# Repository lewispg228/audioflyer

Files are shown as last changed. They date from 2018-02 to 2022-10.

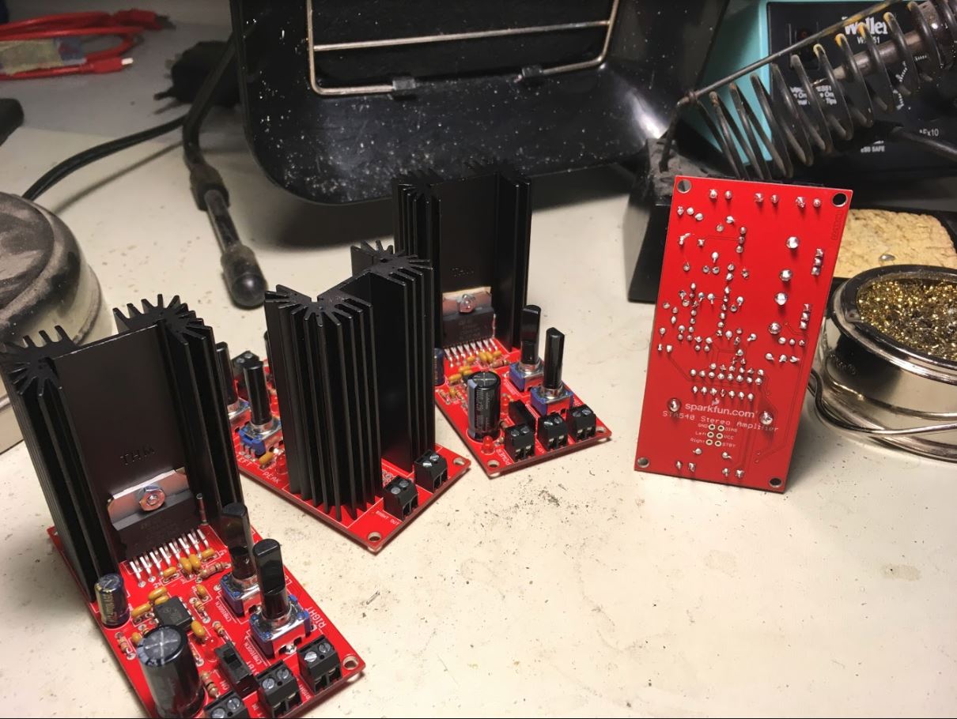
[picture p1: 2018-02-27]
pics/amps_assembled.JPG

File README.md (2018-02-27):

# audioflyer
Surround sound audio mixing controlled by serial commands. Making mixes that fly!

Why? Because this is going to be awesome.

The plan is to use a SparkFun Tsunami Wav Trigger board to play lots of audio files. To start off, I plan to use some tasty guitar riffs and various reverbs/effects. Maybe bass, drums and vocals. We shall see. Then play these tracks through a set of 8 speakers arranged in something similar to 7.1 surround.

For amplification, I am using four SparkFun Audio Amps. They are stereo amps, so this will get me 8 channels.

I hope to start many tracks at the same time, and then control their volume in all 8 tracks with serial commands from a micro controller - probably an arduino. I love the idea of using some code to pull off some smooth motions, spatial movements, rotation of the entire mix around my head, "fly by" guitar solos, and even some volume tricks that may be close to impossible to pull off with manual moving of faders, and a big pain to draw in on automation control tracks. This could mean that I want the snare to spin around my head every time I hit it. It might prove to be annoying, but it might also be totally awesome! What about using the random function in arduino to place where each instrument will live for each mix - it means that every listening experience would be unique - pretty F-in' cool if you ask me.

What got me turned onto this idea was binaural recordings. It's basically a technique that's been around for a long time where you put tiny microphones in your ears (facing outward) or you put them on a dummy head, and then record both mics. When you listen to them back on headphones, you can really hear the position of all the sounds. I guess it has something to do with how our brains calculate time differences and bass roll off difference between each ear. Wild stuff! I bought a pair of these mics from The Sound Professionals for 79 bucks and they sound amazing! I can't wait to track some crazy surround sound mixes and then be able to listen back on headphones anywhere and hear the awesome spatial automation.

This has bound to have been done before... but maybe not? I'm not interested in just rocking 5.1 or 7.1 surround mixes with fancy sound cards and cool plugins. I want to control the entire mix from code on a micro. This will open the door to new sound movement effects that I can't even predict at this time.

All I need is volume control for each track to each output. From reading about the Tsunami, it sounds like this is very possible.

How hard can it be?

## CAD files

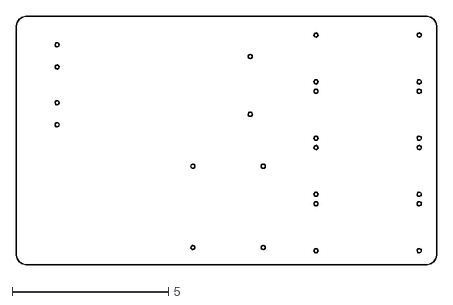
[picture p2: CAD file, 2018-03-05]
base_plate/base_plate.dxf
13.5 x 7.95

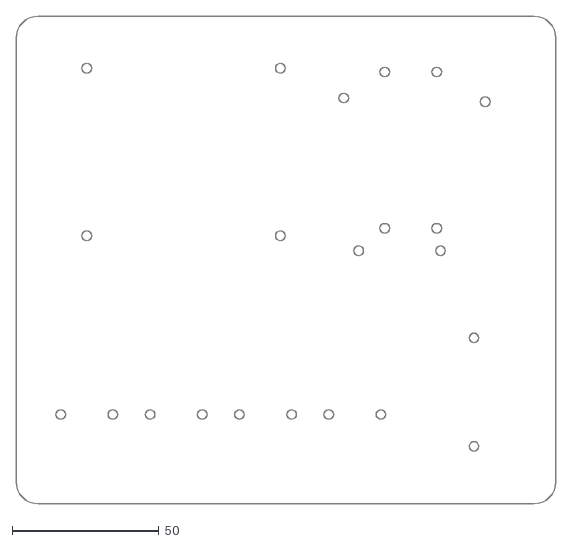
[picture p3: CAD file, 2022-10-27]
base_plate/Noisy_Crickets/base_plate_noisy_crickets.dxf
184.2 x 166.4

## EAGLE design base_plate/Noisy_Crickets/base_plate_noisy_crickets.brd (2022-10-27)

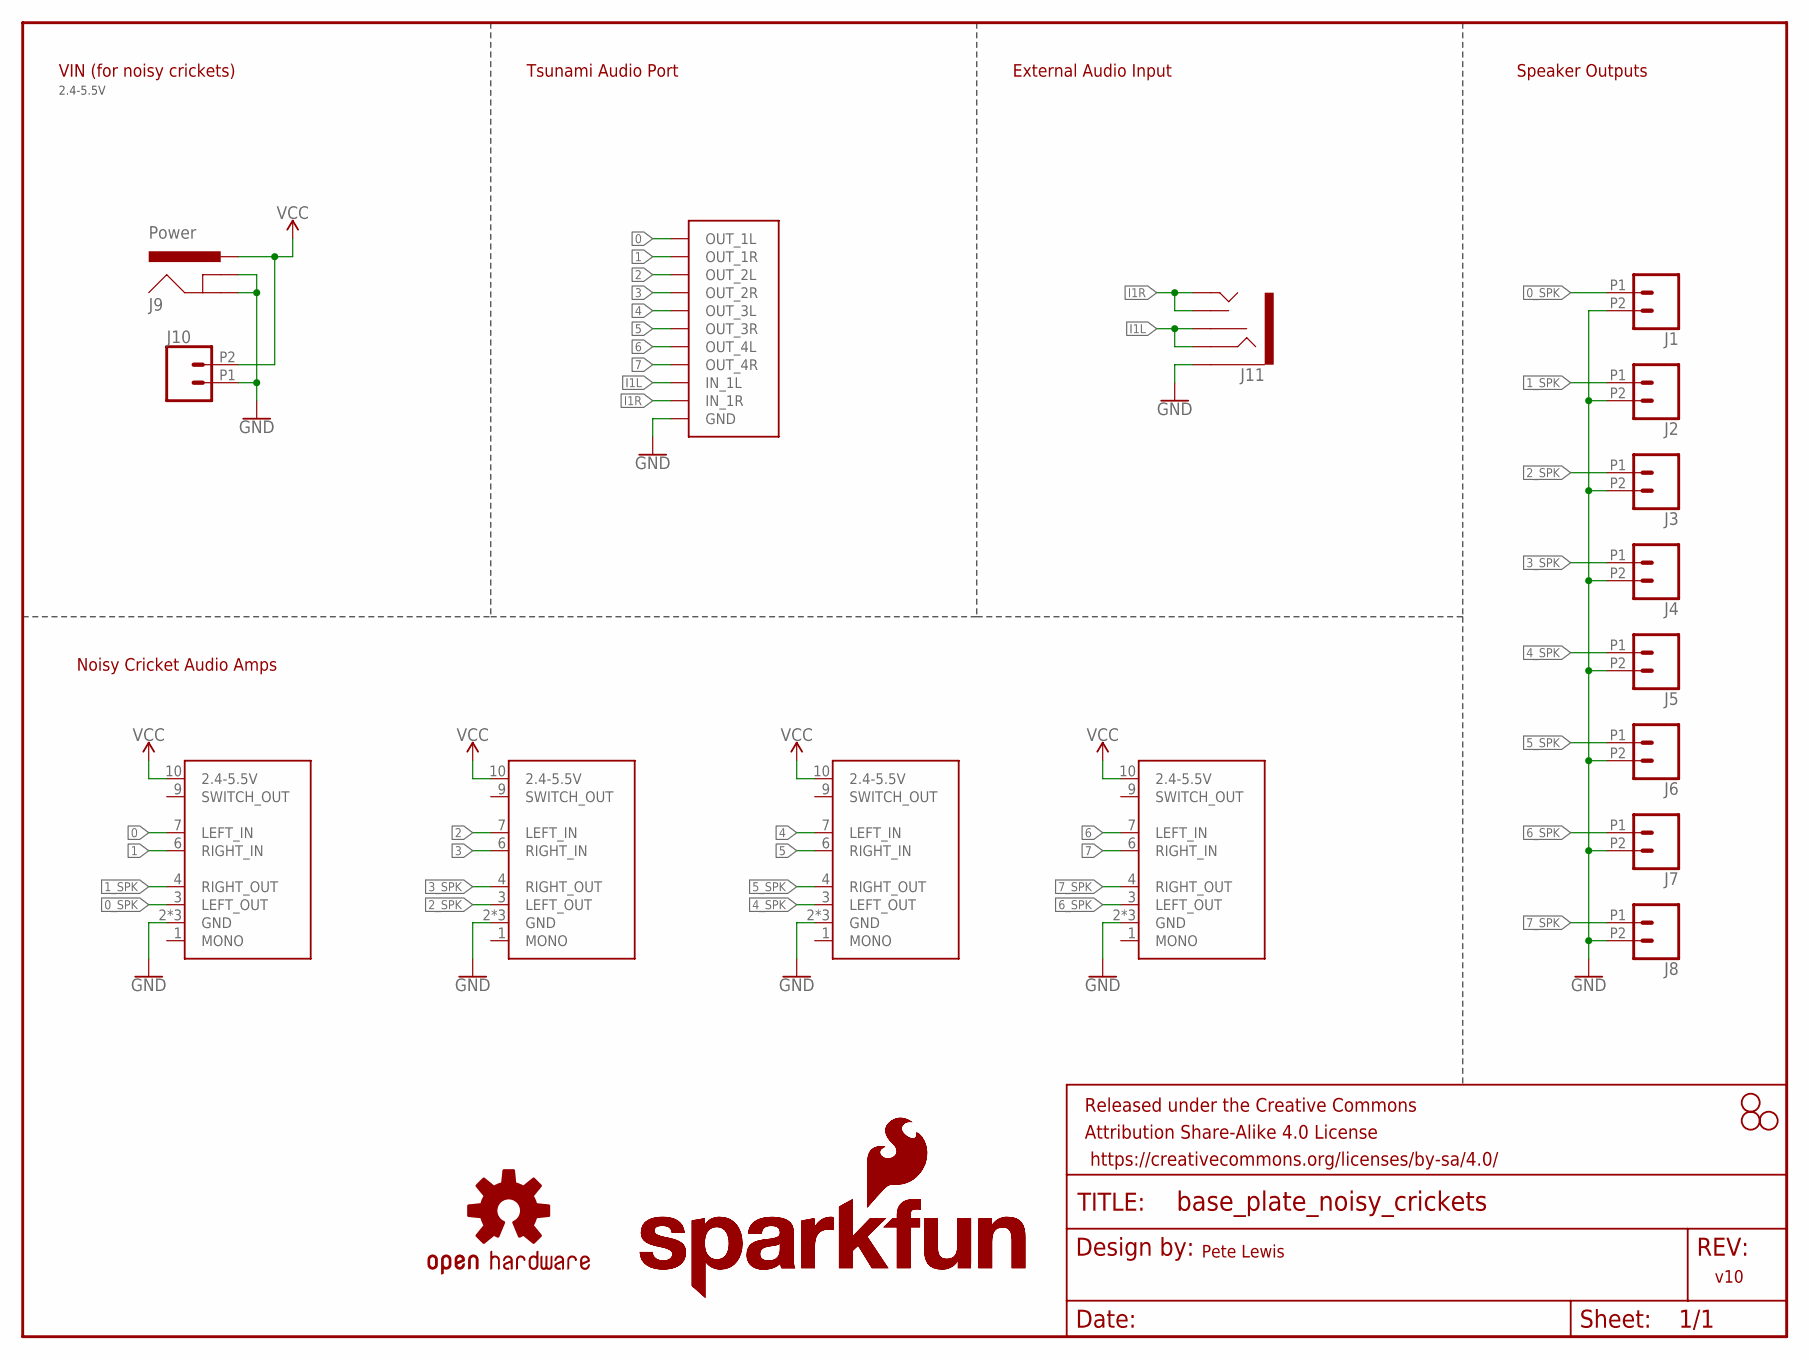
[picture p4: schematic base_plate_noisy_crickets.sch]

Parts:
FRAME1: FRAME-LETTER; CREATIVE_COMMONS
H1, H3, H4: STAND-OFFTIGHT; STAND-OFF-TIGHT
J1, J2, J3, J4, J5, J6, J7, J8, J10: CONN_022.54MM_SCREWTERM; 1X02_2.54_SCREWTERM
J9: Power; POWER_JACK_PTH_LOCK
J11: AUDIO_JACK_3.5MM_PTH; AUDIO-JACK
LOGO1: SFE_LOGO_NAME_FLAME.1_INCH; SFE_LOGO_NAME_FLAME_.1
LOGO2: OSHW-LOGOS; OSHW-LOGO-S
LOGO3: SFE_LOGO_NAME_FLAME.3_INCH; SFE_LOGO_NAME_FLAME_.3
U$1, U$2, U$3, U$4: NOISY_CRICKET; NOISY_CRICKET_W_PTH
U$5: TSUNAMI_AUDIO_PORTS

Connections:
0: U$1.7 (LEFT_IN), U$5.O1L (OUT_1L)
0_SPK: J1.P1 (1), U$1.3 (LEFT_OUT)
1: U$1.6 (RIGHT_IN), U$5.O1R (OUT_1R)
1_SPK: J2.P1 (1), U$1.4 (RIGHT_OUT)
2: U$2.7 (LEFT_IN), U$5.O2L (OUT_2L)
2_SPK: J3.P1 (1), U$2.3 (LEFT_OUT)
3: U$2.6 (RIGHT_IN), U$5.O2R (OUT_2R)
3_SPK: J4.P1 (1), U$2.4 (RIGHT_OUT)
4: U$3.7 (LEFT_IN), U$5.O3L (OUT_3L)
4_SPK: J5.P1 (1), U$3.3 (LEFT_OUT)
5: U$3.6 (RIGHT_IN), U$5.O3R (OUT_3R)
5_SPK: J6.P1 (1), U$3.4 (RIGHT_OUT)
6: U$4.7 (LEFT_IN), U$5.O4L (OUT_4L)
6_SPK: J7.P1 (1), U$4.3 (LEFT_OUT)
7: U$4.6 (RIGHT_IN), U$5.O4R (OUT_4R)
7_SPK: J8.P1 (1), U$4.4 (RIGHT_OUT)
GND: J1.P2 (2), J2.P2 (2), J3.P2 (2), J4.P2 (2), J5.P2 (2), J6.P2 (2), J7.P2 (2), J8.P2 (2), J9.GND, J9.GNDBREAK, J10.P1 (1), J11.SLEEVE, U$1.2 (GND), U$1.5 (GND), U$1.8 (GND), U$2.2 (GND), U$2.5 (GND), U$2.8 (GND), U$3.2 (GND), U$3.5 (GND), U$3.8 (GND), U$4.2 (GND), U$4.5 (GND), U$4.8 (GND), U$5.P$11 (GND), U$5.P$12 (GND), U$5.P$13 (GND), U$5.P$14 (GND), U$5.P$15 (GND), U$5.P$16 (GND), U$5.P$17 (GND), U$5.P$18 (GND), U$5.P$19 (GND), U$5.P$20 (GND)
I1L: J11.RING, J11.RSH, U$5.I1L (IN_1L)
I1R: J11.TIP, J11.TSH, U$5.I1R (IN_1R)
VCC: J9.PWR, J10.P2 (2), U$1.10 (2.4-5.5V), U$2.10 (2.4-5.5V), U$3.10 (2.4-5.5V), U$4.10 (2.4-5.5V)

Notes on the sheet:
Speaker Outputs
Noisy Cricket Audio Amps
VIN (for noisy crickets)
Tsunami Audio Port
External Audio Input
2.4-5.5V
Pete Lewis
v10

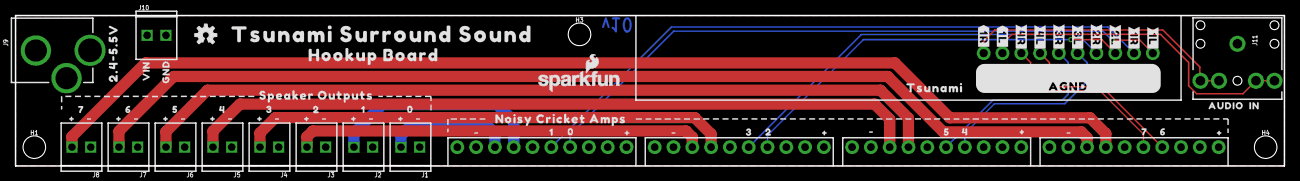
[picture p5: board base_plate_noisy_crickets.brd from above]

Board: 2 copper layers, 171.5 x 20.3 mm, 87 parts (1 on the bottom side), 20 nets.

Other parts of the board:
E$6: REDBOARD_ARTEMIS
E$8: THING_PLUS
U$6: AUDIO0
U$7: IN0
U$8, U$57: 00
U$9, U$58: 10
U$10, U$59: 20
U$11, U$60: 30
U$12, U$61: 40
U$13, U$62: 50
U$14, U$63: 60
U$15, U$64: 70
U$16, U$17, U$18, U$19, U$20, U$21, U$22, U$23, U$49, U$50, U$51, U$52: #0
U$24, U$25, U$26, U$27, U$28, U$29, U$30, U$32, U$48, U$53, U$54, U$55: #_0
U$31: VIN0
U$33: GND0
U$34: TSUNAMI_SURROUND_SOUND0
U$35: HOOKUP_BOARD0
U$36: 2#4#5#5V0
U$37: #AGND#0
U$38: #1R#0
U$39: #2L#0
U$40: #2R#0
U$41: #3R#0
U$42: #3L#0
U$43: #4L#0
U$44: #4R#0
U$45: #1L#0
U$46: NOISY_CRICKET_AMPS0
U$47: TSUNAMI0
U$56: SPEAKER_OUTPUTS0
U$65: TSUNAMI
U$116: #1L#3
U$164: #1R#3

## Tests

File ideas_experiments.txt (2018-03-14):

\\ Magic wand controller.

The participant gets to be in a circle of speakers. Each speaker has a sensor on it to detect if the participant is pointing his/her wand at it. That's where the sound comes from. Imagine mixing a track using this sort of tech. How fun would it be to position the drums/guitar/vocals/lead by pointint where you want them??!!

\\ Spinning speakers.

Put some speakers on a rotating stand - or maybe the speaker is pointint up into a 45 degree mirror that can rotate (to avoid having to deal with cable twisting). This would kind of be like a tremelo effect, but using the room sound to actually effect what you hear. How cool would that be??!!

\\ Listener lazy susan

Rotate the listener? What if I was on a chair that was on a rotating plateform (kind of a large lazy susan), while I record the mix in real time with my binaural mics in. I could rotate physiccally, instead of automating the audio around the speakers.... whoa... this could get wiggy.

\\ tube technology

Put some sounds through long tubes, rotate the tubes, total sonic awesomeness without explaination.

\\ Corrective EQ and (maybe) compression/limiting

Put a DSP chip (blender) that can conduct a hearing test and make a custom EQ per channel, flatten out the speaker, correct for any hearing loss for the listener. Possibly add in some limiting to protect the speakers and allow you to really not worry about maxing out a channel and damaging a speaker or the system in anyway.

\\ magical headphone experience - Realtime automation control to manican head, livestreamed to participant

Have a manican head mic setup with an array of speakers around it. (Use the 3Dio low end maybe?) Stream the audio from the mics to the participant's headphones. This way, the participant can be in a different environment - any room really - and the audio tricks (e/g/ moving the audio position) can happen in real time in the recording room. This would seem like the audio is coming from a speaker that doesn't exhist in the actual room that they are listening in. It would seem magical. Sense their rotational position and adjust the playback room/live stream accordingly.

\\ Blind fold experience?

What if the participant/listener was blind folded, and interacted with the space with either a magic wand or some sort of touch sensative surfaces (walls? Joystick?). Audio experience to the max. Tell a story by flying through the space. Make it a game to point where you think you hear the sound.

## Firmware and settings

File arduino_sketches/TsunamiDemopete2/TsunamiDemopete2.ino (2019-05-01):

// ****************************************************************************
//       Sketch: Tsunami Serial Control Example
// Date Created: 11/22/2016
//
//     Comments: Demonstrates advanced, two-way, serial control of the Tsunami
//               from a 3.3V Arduino.
//
//  Programmers: Jamie Robertson, info@robertsonics.com
//
//  WARNING: The Tsunami is a 3.3V device. Attempting to connect it to a 5V
//   Arduino (such as an UNO) without level-shifters, will likely damage your
//   Tsunami!
//
// ****************************************************************************
//
// To use this sketch with an Arduino, you'll need:
//
// 1) An Arduino with an operating voltage of 3.3V, *** NOT 5V ***!
// 2) Download and install the Metro library.
// 3) Connect 3 wires from the Arduino to the Tsunami's serial connector:
//
//    Arduino       Tsunami
//    =======       =======
//    GND  <------> GND
//    TXn  <------> RX
//    RXn  <------> TX
//
//    If you're using an Arduino with at least one extra hardware serial port,
//    such as an M0 or Teensy, the Tsunami library is already set to use
//    Serial1. If you need to change that, or want to use AltSoftSerial, you
//    must make a small edit the Tsunami.h file, according the instructions in
//    that file.
//
// 4) Download and install the demo wav files onto the Tsunami's microSD
//    card. You can find them here:
//
//    http://robertsonics.com/2015/04/25/arduino-serial-control-tutorial/
//
//    You can certainly use your own tracks instead, although the demo may
//    not make as much sense. If you do, make sure your tracks are at least
//    10 to 20 seconds long and have no silence at the start of the file.
//
// 5) Open the Arduino Serial Monitor window to see status messages.

#include <Metro.h>              // Include the Metro library header
#include <Tsunami.h>            // Include the Tsunami library header
#include <AltSoftSerial.h>    // Optional for using AltSoftSerial

#define LED 13                  // our LED

Tsunami tsunami;                // Our Tsunami object

Metro gLedMetro(500);           // LED blink interval timer
Metro gSeqMetro(6000);          // Sequencer state machine interval timer

byte gLedState = 0;             // LED State
int  gSeqState = 0;             // Main program sequencer state
int  gRateOffset = 0;           // Tsunami sample-rate offset
int  gNumTracks;                // Number of tracks on SD card

int delay_time = 100;

char gTsunamiVersion[VERSION_STRING_LEN];    // Tsunami version string


// ****************************************************************************
void setup() {
  
  // Serial monitor
  Serial.begin(9600);
 
  // Initialize the LED pin
  pinMode(LED,OUTPUT);
  digitalWrite(LED,gLedState);

  // We should wait for the Tsunami to finish reset before trying to send
  // commands.
  delay(1000);

  // Tsunami startup at 57600
  tsunami.start();
  delay(10);
  
  // Send a stop-all command and reset the sample-rate offset, in case we have
  //  reset while the Tsunami was already playing.
  tsunami.stopAllTracks();
  tsunami.samplerateOffset(0, 0);
  
  // Enable track reporting from the Tsunami
  tsunami.setReporting(true);
  
  // Allow time for the Tsunami to respond with the version string and
  //  number of tracks.
  delay(100); 
  
}


// ****************************************************************************
// This program uses a Metro timer to create a sequencer that steps through
//  states at 6 second intervals - you can change this rate above. Each state
//  Each state will demonstrate a Tsunami serial control feature.
//
//  In this example, some states wait for specific audio tracks to stop playing
//  before advancing to the next state.

void loop() {
  
int i;

  // Call update on the Tsunami to keep the track playing status current.
  tsunami.update();
  
  // Check if the sequencer timer has elapsed and perform the appropriate
  //  state action if so. States 3 and 5 wait for tracks to stop playing and
  //  are therefore not in the metro event. They are instead polled after the
  //  metro check.
  if (gSeqMetro.check() == 1) {
      
      switch (gSeqState) {
  
          // State 0: Demonstrates how to fade in a music track 
          case 0:
              delay_time = 10;
              // First retrieve and print the version and number of tracks        
              if (tsunami.getVersion(gTsunamiVersion, VERSION_STRING_LEN)) {
                  Serial.print(gTsunamiVersion);
                  Serial.print("\n");
                  gNumTracks = tsunami.getNumTracks();
                  Serial.print("Number of tracks = ");
                  Serial.print(gNumTracks);
                  Serial.print("\n");
              }
              else
                  Serial.print("WAV Trigger response not available");
              delay(delay_time);
              Serial.print("1");
              tsunami.stopAllTracks();
              tsunami.samplerateOffset(0, 0);        // Reset sample rate offset to 0
              delay(delay_time);
              Serial.print("2");
              tsunami.masterGain(0, 0);              // Reset the master gain to 0dB
              delay(delay_time);
              Serial.print("3");
              tsunami.trackGain(1, -40);             // Preset Track 2 gain to -40dB
              tsunami.trackGain(2, -40);
              delay(delay_time);
              Serial.print("4");
              tsunami.trackPlayPoly(1, 0, true);     // Start Track 2
              tsunami.trackPlayPoly(2, 1, true);
              delay(delay_time);
              tsunami.trackFade(1, 0, 50, false);  // Fade Track 2 to 0dB over 2 sec
              tsunami.trackFade(2, 0, 50, false);
              gSeqState = 1;                         // Advance to state 1
              while(1);
          break;

          // State 1: Demonstrates how to cross-fade music tracks
          case 1:
              Serial.print("5");
              tsunami.trackGain(1, -40);             // Preset Track 1 gain to -40dB
              tsunami.trackPlayPoly(1, 0, true);     // Start Track 1
              tsunami.trackFade(1, 0, 3000, false);  // Fade Track 1 up to 0db over 3 secs
              tsunami.update();
              delay(2000);                           // Wait 2 secs
              tsunami.trackFade(1, -40, 3000, true); // Fade Track 2 down to -40dB over 3 secs and stop
              //Serial.print("Waiting for Track 1 to finish... ");
              gSeqState = 3;                         // Advance to state 2
          break;
                                 
          // State 3: Honk the horn 2 times
          case 3:
              tsunami.trackPlayPoly(5, 0, true);     // Start Track 5 poly
              tsunami.update();
              delay(500);
              tsunami.trackStop(5);                  // Stop Track 5
              tsunami.update();
              delay(250);
              tsunami.trackPlayPoly(5, 0, true);     // Start Track 5 poly
              tsunami.update();
              delay(500);
              tsunami.trackStop(5);                  // Stop Track 5
              gSeqState = 4;                         // Advance to state 4
          break;
          
          // State 4: Fade out and stop dialog
          case 4:
              tsunami.trackLoop(4, 0);               // Disable Track 4 looping
              tsunami.trackFade(4, -50, 5000, true); // Fade Track 4 to -50dB and stop
              Serial.print("Waiting for Track 4 to finish... ");
              gSeqState = 5;                         // Advance to state 5
          break;
            
          // State 6: Demonstrates preloading tracks and starting them in sample-
          //  sync, and real-time samplerate control (pitch bending);
          case 6:
              tsunami.trackLoad(6, 0, true);         // Load and pause Track 6
              tsunami.trackLoad(7, 0, true);         // Load and pause Track 7
              tsunami.trackLoad(8, 0, true);         // Load and pause Track 8
              tsunami.resumeAllInSync();             // Start all in sample sync

              // Decrement the sample rate offset from 0 to -32767 (1 octave down)
              //  in 10 ms steps
              gRateOffset = 0;
              for (i = 0; i < 127; i++) {
                gRateOffset -= 256;
                tsunami.samplerateOffset(0, gRateOffset);
                delay(10);
              }
              gRateOffset = -32767;
              tsunami.samplerateOffset(0, gRateOffset);
              
              // Hold for 1 second
              delay(1000);
              
              // Now increment to +32767 (1 octave up) in 10ms steps
              for (i = 0; i < 255; i++) {
                gRateOffset += 256;
                tsunami.samplerateOffset(0, gRateOffset);
                delay(10);
              }
              gRateOffset = 32767;
              tsunami.samplerateOffset(0, gRateOffset);
              
              // Hold for 1 second, the stop all tracks
              delay(1000);
              tsunami.stopAllTracks();               // Stop all
              gSeqState = 0;                         // Advance to state 0
          break;
            
      } // switch
           
  } // if (gSeqState.check() == 1)
 
  // State 2: Wait for Track 2 to stop, then fade down the music and start the
  //  dialog track looping.
  if (gSeqState == 2) {
      gSeqMetro.reset();                             // Reset the sequencer metro
      if (!tsunami.isTrackPlaying(2)) {
          Serial.print("Track 2 done\n");
          tsunami.trackFade(1, -6, 500, false);      // Lower the music volume
          tsunami.trackLoop(4, 1);                   // Enable Track 4 looping
          tsunami.trackPlayPoly(4, 0, true);         // Start Track 4 poly
          gSeqState = 3;                             // Advance to state 3;
      }       
  }

  // State 5: Wait for Track 4 to stop, then play three tracks sequentially and
  //  stop all with a 5 sec fade to -50dB. This is how you can implement MIDI
  //  Note-On/Off control for: MIDI -> Arduino -> WAV Trigger.
  if (gSeqState == 5) {
      gSeqMetro.reset();
      if (!tsunami.isTrackPlaying(4)) {
          Serial.print("Track 4 done\n");
          tsunami.masterGain(0, -8);                 // Lower main volume
          tsunami.trackPlayPoly(6, 0, true);         // Play first note
          tsunami.update();
          delay(1000);
          tsunami.trackPlayPoly(7, 0, true);         // Play second note
          tsunami.update();
          delay(1000);
          tsunami.trackPlayPoly(8, 0, true);         // Play third note
          tsunami.update();
          delay(1000);
          tsunami.trackFade(6, -50, 5000, true);     // Fade Track 6 to -50dB and stop
          tsunami.trackFade(7, -50, 5000, true);     // Fade Track 7 to -50dB and stop
          tsunami.trackFade(8, -50, 5000, true);     // Fade Track 8 to -50dB and stop
          gSeqState = 6;
      }       
  }
  
  // If time to do so, toggle the LED
  if (gLedMetro.check() == 1) {
      if (gLedState == 0) gLedState = 1;
      else gLedState = 0;
      digitalWrite(LED, gLedState);
  } // if (gLedMetro.check() == 1)

  // Delay 30 msecs
  delay(30);
}

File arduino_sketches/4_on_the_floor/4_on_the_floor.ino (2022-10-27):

/*
  Audio Flyer
  SparkFun Electronics
  Pete Lewis
  Started: 5-18-2021
*/
#include "track_numbers.h"
#include "drum_beats.h"
#include "set_functions.h"

int delay_ms_tsunami_com = 10;

#include <Tsunami.h>            // Include the Tsunami library header
//#include <AltSoftSerial.h>    // Optional for using AltSoftSerial

Tsunami tsunami;                // Our Tsunami object

char gTsunamiVersion[VERSION_STRING_LEN];    // Tsunami version string
int  gNumTracks;                // Number of tracks on SD card

long bpm = 120; // beats per minute (how many 1/4 notes there are in a minute)

bool guitar_qued = 0;
int guitar_qued_track = 20;
int guitar_qued_channel = 0;

bool bass_qued = 0;
int bass_qued_track = 100;
int bass_qued_channel = 0;

void setup()
{

  Serial.begin(115200);
  Serial.println("Audio Flyer DEBUG ON");

  tsunami.start();
  delay(delay_ms_tsunami_com);
  // Send a stop-all command and reset the sample-rate offset, in case we have
  //  reset while the Tsunami was already playing.
  tsunami.stopAllTracks();
  delay(delay_ms_tsunami_com);
  tsunami.samplerateOffset(0, 0);
  delay(delay_ms_tsunami_com);
  tsunami.setReporting(false); // disable track reporting from the Tsunami
  delay(delay_ms_tsunami_com);
  tsunami.update(); // Call update to keep the track playing status current.
  delay(delay_ms_tsunami_com);
  tsunami.masterGain(0, 0); // Reset the master gain to 0dB
  delay(delay_ms_tsunami_com);

  if (tsunami.getVersion(gTsunamiVersion, VERSION_STRING_LEN)) {
    Serial.print(gTsunamiVersion);
    Serial.print("\n");
    gNumTracks = tsunami.getNumTracks();
    Serial.print("Number of tracks = ");
    Serial.print(gNumTracks);
    Serial.print("\n");
  }


  test_audio_playback();
  pinMode(2, INPUT_PULLUP);
}

void loop()
{

  while (digitalRead(2) == false) // if ya press hte button on D2, then it will play a cycle of the song...
  {
    set_four_on_the_floor();
    // guitar
    guitar_qued = 1;
    guitar_qued_track = 20;
    guitar_qued_channel = 1;
    // bass
    bass_qued = 1;
    bass_qued_track = 100;
    bass_qued_channel = 2;

    play_measure();
    guitar_qued_track = 21;
    guitar_qued = 1;
    guitar_qued_channel = random(3, 6);
    play_measure();
    play_measure();
    play_measure();

    // guitar
    guitar_qued = 1;
    guitar_qued_track = 20;
    guitar_qued_channel = 1;
    // bass
    bass_qued = 1;
    bass_qued_track = 100;
    bass_qued_channel = 2;

    play_measure();
    guitar_qued_track = 21;
    guitar_qued = 1;
    guitar_qued_channel = random(3, 6);
    play_measure();
    play_measure();
    play_measure();

    set_half_time_groove_ride();
    // guitar
    guitar_qued = 1;
    guitar_qued_track = 203;
    guitar_qued_channel = 1;
    // bass
    bass_qued = 1;
    bass_qued_track = 202;
    bass_qued_channel = 2;

    for(int i = 0 ; i < 8 ; i++)
    {
      play_measure();
    }
  }
}

void test_audio_playback()
{
  for (int i = 0 ; i < 8 ; i++)
  {
    //int track = i + 60; // 60 is the strat of some drum tracks
    //int channel = i; // play a track on each output (0-7)
    //Serial.print("track: ");
    //Serial.println(track);
    //tsunami.trackGain(track, -5);
    //delay(delay_ms_tsunami_com);
    //tsunami.trackPlayPoly(track, channel, false);
    play_track((11), i);
    delay(1000);
  }
}

void play_track(int track = 1, int channel = 0);

void play_track(int track, int channel)
{
  Serial.print("track: ");
  Serial.println(track);
  tsunami.trackGain(track, -5);
  delay(delay_ms_tsunami_com);
  tsunami.trackPlayPoly(track, channel, false);
  delay(delay_ms_tsunami_com);
}





void play_measure()
{
  // loop through all 16th bar time divisions,
  // play each WAV (or combo of WAVS) at each division.

  long start_time_micros = micros();

  for (int i = 0 ; i < 16 ; i++)
  {
    //int val = analogRead(A0);
    //bpm = map(val, 0, 1023, 0, 240);
    bpm = 134;
    Serial.print("bpm: ");
    Serial.println(bpm);

    if (kick[i] == 1) tsunami.trackLoad(kick_t, 0, false);
    delay(delay_ms_tsunami_com);
    if (snare[i] == 1) tsunami.trackLoad(snare_t, 0, false);
    delay(delay_ms_tsunami_com);
    if (hat[i] == 1) tsunami.trackLoad(hat_t, 0, false);
    delay(delay_ms_tsunami_com);
    if (ride[i] == 1) tsunami.trackLoad(ride_t, 0, false);
    delay(delay_ms_tsunami_com);
    if (guitar_qued == 1)
    {
      tsunami.trackLoad(guitar_qued_track, guitar_qued_channel, false);
      delay(delay_ms_tsunami_com);
      tsunami.trackGain(20, -5);
      guitar_qued = 0;
    }

    if (bass_qued == 1)
    {
      tsunami.trackLoad(bass_qued_track, bass_qued_channel, false);
      delay(delay_ms_tsunami_com);
      tsunami.trackGain(100, 10);
      delay(delay_ms_tsunami_com);
      tsunami.trackGain(202, 10);
      bass_qued = 0;
    }

    delay(delay_ms_tsunami_com);
    tsunami.resumeAllInSync();

    long sixteenth_note_delay = bpm_to_16th_delayms(bpm);
    while ((micros() - start_time_micros) < (sixteenth_note_delay * 1000)) delayMicroseconds(1);
    start_time_micros = micros();
  }
}

long bpm_to_16th_delayms(long bpm)
{
  float seconds_f = 60.0 / float(bpm) ; // beats-per-minute to beats-per-second
  seconds_f /= 4.0; // to quarter notes
  seconds_f *= 1000.0; // to milliseconds
  return long(seconds_f);
}

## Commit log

2018-02-27 pic of amps and baseplate layout
    [base_plate.brd]
2018-03-05 tweaked base plate and exported to dxf
    [base_plate.brd, base_plate.dxf]
2018-03-20 got some audio playing from arduino example wahoo!!
    still no luck with python attempt, but at least I know that my hardware
    is working.
    Also tried out some reverb ideas, but it didn't realy sound that good.
    I'm wondering if some of the dry track needs to be in the reverb tracks
    too.
    [TsunamiDemoPete.ino, TsunamiDemopete2.ino, fadelr.ino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]
2022-10-27 4 on the floor example and base plate design
    [base_plate_noisy_crickets.GBL, base_plate_noisy_crickets.GBO, base_plate_noisy_crickets.GBP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]

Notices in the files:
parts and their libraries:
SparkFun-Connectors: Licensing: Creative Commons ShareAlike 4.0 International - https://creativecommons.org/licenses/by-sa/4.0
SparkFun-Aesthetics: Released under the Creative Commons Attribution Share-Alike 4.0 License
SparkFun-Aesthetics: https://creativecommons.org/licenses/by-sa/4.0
